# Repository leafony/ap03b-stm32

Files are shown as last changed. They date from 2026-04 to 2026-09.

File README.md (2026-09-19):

# Leafony AP03B STM32

STM32L452REI6を搭載した、Leafony AP03B STM32リーフのハードウェア設計リポジトリです。KiCadの回路図・PCBレイアウト、専用ライブラリ、部品表（BOM）を収録しています。

設計を開く場合は [KiCadプロジェクト](./kicad/leafony-ap03-stm32.kicad_pro)、部品を確認する場合は [BOM](./docs/leafony-ap03b-stm32-bom.csv) から参照してください。

## ハードウェア概要

| 項目 | 内容 |
| --- | --- |
| MCU | STMicroelectronics STM32L452REI6（U1） |
| CPU | Arm Cortex-M4、FPU搭載、最大80 MHz |
| メモリ | Flash 512 KB / SRAM 160 KB |
| MCUパッケージ | UFBGA-64、5 × 5 mm、0.5 mmピッチ |
| 低速外部クロック | 32.768 kHz水晶（X1） |
| 電源 | Leafonyバスの3.3 V / GND |
| バス接点 | CN1、表裏各29接点 |
| 主なバス信号 | D0〜D13、A0〜A5、SDA / SCL、SWDIO / SWCLK、RESET、AREF |
| 操作・表示 | BOOT0切り替えスイッチ、リセットスイッチ、BOOT0状態表示LED |
| 基板 | 20 × 20 mm、6層、板厚0.8 mm（PCB設計値） |
| 設計リビジョン | v1.0、2026-04-27（単体基板・回路図のタイトル欄） |

CPU・メモリの仕様は [STMicroelectronicsの製品情報](https://www.st.com/en/microcontrollers-microprocessors/stm32l452re.html)、実装部品と接続は本リポジトリの回路図・PCB・BOMを参照しています。最大クロックはMCUの仕様値で、実際の動作クロックはファームウェアの設定によります。

CN1のVBUS端子は未接続で、AREFの接続用抵抗R5は未実装（DNP）です。各端子の接続は [Leafonyバス回路図](./kicad/leafony_bus.kicad_sch) と [MCU回路図](./kicad/stm32.kicad_sch) で確認できます。

### スイッチとLED

| 部品 | 型番 | 回路上の役割 |
| --- | --- | --- |
| SW1（PG） | CUS-12TB | BOOT0のHigh / Lowを切り替える |
| SW2（RST） | EVQ-P7B01P | 押すとRESETをGNDへ接続する |
| D1 | SML-A12U8TT86 | BOOT0がHighのときに点灯する |

詳細は [リセット・プログラム切り替え回路](./kicad/reset_prog.kicad_sch) を参照してください。

## リポジトリ構成

| パス | 内容 |
| --- | --- |
| [kicad/leafony-ap03-stm32.kicad_pro](./kicad/leafony-ap03-stm32.kicad_pro) | 単体基板のKiCadプロジェクト |
| [kicad/leafony-ap03-stm32.kicad_sch](./kicad/leafony-ap03-stm32.kicad_sch) | トップレベル回路図。以下の3シートをまとめる |
| [kicad/stm32.kicad_sch](./kicad/stm32.kicad_sch) | MCU、電源、クロック周辺回路 |
| [kicad/leafony_bus.kicad_sch](./kicad/leafony_bus.kicad_sch) | Leafonyバス接点と信号接続 |
| [kicad/reset_prog.kicad_sch](./kicad/reset_prog.kicad_sch) | リセット、BOOT0切り替え、LED、信号切り替え回路 |
| [kicad/leafony-ap03-stm32.kicad_pcb](./kicad/leafony-ap03-stm32.kicad_pcb) | 単体基板のPCBレイアウト |
| [kicad/panelized/](./kicad/panelized/) | 面付け基板のプロジェクト・PCBレイアウト |
| [kicad/lib/](./kicad/lib/) | Leafony専用シンボル、フットプリント、3Dモデル配置先 |
| [docs/leafony-ap03b-stm32-bom.csv](./docs/leafony-ap03b-stm32-bom.csv) | 部品表（CSV） |
| [examples/](./examples/) | サンプルコード用ディレクトリ。現時点ではコード未収録 |

製品名はAP03Bですが、KiCadファイル名は `leafony-ap03-stm32` です。

## KiCadで開く

回路図とPCBは **KiCad 9.0** で保存されています。KiCad 9.0形式を読み込める環境と、KiCad標準のシンボル・フットプリントライブラリを用意してください。

1. リポジトリを取得します。

   ```sh
   git clone https://github.com/leafony/ap03b-stm32.git
   cd ap03b-stm32
   ```

2. KiCadで `kicad/leafony-ap03-stm32.kicad_pro` を開きます。
3. プロジェクト内の `.kicad_sch` を開くと回路図、`.kicad_pcb` を開くと基板レイアウトを確認できます。
4. 回路図のトップシートから「STM32 MCU」「Leafony Bus」「Reset Prog」の各階層シートへ移動します。

専用ライブラリは [sym-lib-table](./kicad/sym-lib-table) と [fp-lib-table](./kicad/fp-lib-table) に登録済みです。どちらも `${KIPRJMOD}/lib/` を参照するため、`kicad/` 以下のディレクトリ構成を保って開いてください。

### 面付け基板について

`kicad/panelized/` のPCBタイトル欄は「Leafony AP03 STM32 / 2025-07-06」で、単体基板の「Leafony AP03B STM32 / 2026-04-27」と異なります。製造に使用する場合は、単体基板の変更が反映されているか確認してください。

面付けプロジェクトを開くと `${KIPRJMOD}` の基準は `kicad/panelized/` になります。3Dモデルを表示する場合は、参照先が `kicad/lib/3dmodels/` に解決されるようにモデルパスを調整してください。

## 部品表（BOM）

[BOMのCSV](./docs/leafony-ap03b-stm32-bom.csv) には、部品番号（Reference）、値・型番（Value）、データシート、フットプリント、数量（Qty）、実装対象外の指定（DNP）、メーカー品番（MPN）、メーカー名（MANUFACTURER）を記載しています。

- `R5`、`R7`、`R12`、`R14` はDNP（未実装）です。
- `CN1` はBOMに含まれていません。バス接点の形状・接続は回路図とPCBを参照してください。
- 部品を変更した場合は、回路図と合わせてBOMも更新してください。

## 3Dモデルについて

一部部品の3Dモデルはライセンスの都合上公開できません。`kicad/lib/3dmodels/` にはモデル本体を収録していないため、必要に応じて別途入手し、以下のファイル名で配置してください。Leafony専用の回路図シンボルとフットプリントは同梱しています。

単体基板のPCBが参照するモデルは次のとおりです。

| 部品 | ファイル名（`kicad/lib/3dmodels/` 内） |
| --- | --- |
| U1：STM32L452REI6 | `UFBGA64-5x5mm.step` |
| U2：TS3A4751RUCR | `RUC0014A.stp` |
| SW1：CUS-12TB | `CUS-12TB.step` |
| SW2：EVQ-P7B01P | `EVQP7-KB-01P.STEP` |
| X1：32.768 kHz水晶 | `XTAL_NX2012SA_NDK.step` |
| Q1：RE1C002UNTCL | `DIO_RB558WMF_ROM.step` |
| D1：SML-A12U8TT86 | `SML-A12U8TT86P.stp` |

モデル名は既存のPCB参照に合わせたものです。入手したモデルのパッケージ形状を確認し、PCBエディターの3Dビューアーで位置・向き・縮尺を確認してください。3Dモデルがなくても回路図やPCBレイアウトは確認できます。

標準部品のモデルには `${KICAD8_3DMODEL_DIR}` の参照が残っています。KiCad 9では、旧バージョンの変数が未定義なら現行バージョンの対応する変数へ自動解決されます。表示されない場合は、標準3Dモデルライブラリの導入状況と「パスを設定」で古いパスが明示設定されていないか確認してください。詳細は [KiCad公式ドキュメントのパス設定](https://docs.kicad.org/9.0/en/kicad/kicad.html) を参照してください。

## ファームウェア・関連資料

このリポジトリには、ファームウェアのビルド設定や書き込みスクリプト、実行可能なサンプルコードは含まれていません。STM32 MCUリーフの開発環境については、Leafony公式資料を参照してください。

- [STM32 MCU スタートガイド](https://docs.leafony.com/getting-started/stm32/)
- [STM32 MCU向けArduino IDEの設定](https://docs.leafony.com/environment/stm32/arduino_ide/)
- [AP03 STM32 MCU 技術資料](https://docs.leafony.com/leaf/processor/ap03/)

上記のAP03向け資料を利用する際は、本リポジトリのAP03B回路図でピン接続や実装部品を確認してください。

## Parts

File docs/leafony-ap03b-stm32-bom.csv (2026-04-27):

Reference | Value | Datasheet | Footprint | Qty | DNP | MPN | MANUFACTURER
C1,C4,C6,C7,C8,C10 | 100nF(K)25V X5R | https://search.murata.co.jp/Ceramy/image/img/A01X/G101/ENG/GRM033R61E104KE14-01.pdf | Capacitor_SMD:C_0201_0603Metric | 6 |  | GRM033R61E104KE14D | Murata Electronics
C2,C3 | 6pF(D)50V C0G/NP0 | https://search.murata.co.jp/Ceramy/image/img/A01X/G101/ENG/GRM1555C1H6R0DA01-01.pdf | Capacitor_SMD:C_0402_1005Metric | 2 |  | GRM1555C1H6R0DA01D | Murata Electronics
C5 | 1uF(K)16V X6S | https://search.murata.co.jp/Ceramy/image/img/A01X/G101/ENG/GRM155C81C105KE11-01.pdf | Capacitor_SMD:C_0402_1005Metric | 1 |  | GRM155C81C105KE11D | Murata Electronics
C9 | 10uF(K)25V X5R | https://search.murata.co.jp/Ceramy/image/img/A01X/G101/ENG/GRM188R61E106KA73-01.pdf | Capacitor_SMD:C_0603_1608Metric | 1 |  | GRM188R61E106KA73D | Murata Electronics
C11 | 470nF(K)50V X5R | https://search.murata.co.jp/Ceramy/image/img/A01X/G101/ENG/GRM155R61H474KE11-01.pdf | Capacitor_SMD:C_0402_1005Metric | 1 |  | GRM155R61H474KE11D | Murata Electronics
D1 | SML-A12U8TT86 | https://fscdn.rohm.com/en/products/databook/datasheet/opto/led/chip_mono/sml-a12_a13.pdf | Leafony:LED_SML-A12_ROM | 1 |  | SML-A12U8TT86 | Rohm Semiconductor
D2 | 1SS387,L3F | https://toshiba.semicon-storage.com/info/1SS387_datasheet_en_20240617.pdf | Diode_SMD:D_SOD-523 | 1 |  | 1SS387,L3F | Toshiba Semiconductor and Storage
FB1 | MPZ1005S300CT000 | https://product.tdk.com/system/files/dam/doc/product/emc/emc/beads/catalog/emc_emc_mpz_en.pdf | Fuse:Fuse_0402_1005Metric | 1 |  | MPZ1005S300CT000 | TDK Corporation
Q1 | RE1C002UNTCL | https://fscdn.rohm.com/en/products/databook/datasheet/discrete/transistor/mosfet/re1c002un-e.pdf | Leafony:DIO_RB558WMF_ROM | 1 |  | RE1C002UNTCL | Rohm Semiconductor
R1,R2,R3,R8 | 10k(F) | https://www.yageo.com/upload/media/product/productsearch/datasheet/rchip/PYu-RC_Group_51_RoHS_L_12.pdf | Resistor_SMD:R_0402_1005Metric | 4 |  | RC0402FR-0710KL | YAGEO
R4,R11,R13 | 0R | https://www.yageo.com/upload/media/product/productsearch/datasheet/rchip/PYu-RC_Group_51_RoHS_L_12.pdf | Resistor_SMD:R_0402_1005Metric | 3 |  | RC0402JR-070RL | YAGEO
R5,R7,R12,R14 | DNP | ~ | Resistor_SMD:R_0402_1005Metric | 4 | DNP
R6 | 1k(F) | https://www.yageo.com/upload/media/product/productsearch/datasheet/rchip/PYu-RC_Group_51_RoHS_L_12.pdf | Resistor_SMD:R_0402_1005Metric | 1 |  | RC0402FR-071KL | YAGEO
R9 | 100R(F) | https://www.yageo.com/upload/media/product/productsearch/datasheet/rchip/PYu-RC_Group_51_RoHS_L_12.pdf | Resistor_SMD:R_0402_1005Metric | 1 |  | RC0402FR-07100RL | YAGEO
R10 | 100k(F) | https://www.yageo.com/upload/media/product/productsearch/datasheet/rchip/PYu-RC_Group_51_RoHS_L_12.pdf | Resistor_SMD:R_0402_1005Metric | 1 |  | RC0402FR-07100KL | YAGEO
SW1 | CUS-12TB | https://www.nidec-copal-electronics.com/eng/wp-content/uploads/2020/02/cus_e.pdf | Leafony:CUS-12TB_NDC | 1 |  | CUS-12TB | Nidec Components Corporation
SW2 | EVQ-P7B01P | https://industrial.panasonic.com/cdbs/www-data/pdf/ATK0000/ATK0000CE3.pdf | Leafony:EVQ-P7B01P | 1 |  | EVQ-P7B01P | Panasonic Electronic Components
U1 | STM32L452REI6 | https://www.st.com/resource/en/datasheet/stm32l452re.pdf | Package_BGA:UFBGA-64_5x5mm_Layout8x8_P0.5mm | 1 |  | STM32L452REI6 | STMicroelectronics
U2 | TS3A4751RUCR | https://www.ti.com/lit/gpn/ts3a4751 | Leafony:RUC14 | 1 |  | TS3A4751RUCR | Texas Instruments
X1 | MU00530-32.768K | https://www.ndk.com/images/products/catalog/c_NX2012SA-EXS00A_e.pdf | Crystal:Crystal_SMD_2012-2Pin_2.0x1.2mm | 1 |  | MU00530-32.768K | NDK America, Inc.

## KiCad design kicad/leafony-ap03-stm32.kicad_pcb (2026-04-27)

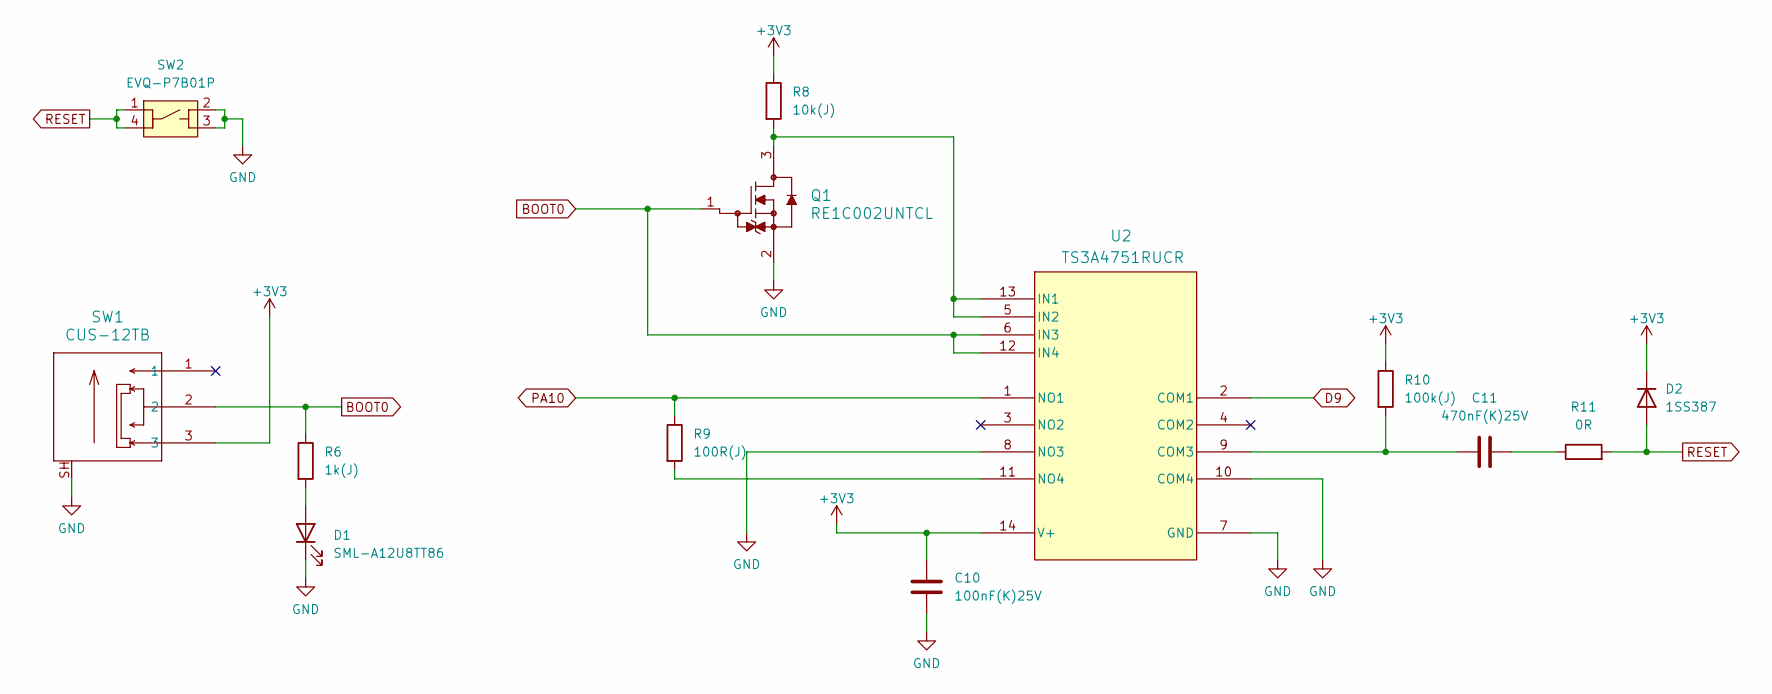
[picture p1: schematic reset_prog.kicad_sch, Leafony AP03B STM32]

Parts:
C10: 100nF(K)25V; C_0201_0603Metric
C11: 470nF(K)25V; C_0402_1005Metric
D1: SML-A12U8TT86; LED_SML-A12_ROM
D2: 1SS387; D_SOD-523
Q1: RE1C002UNTCL; DIO_RB558WMF_ROM
R6: 1k(J); R_0402_1005Metric
R8: 10k(J); R_0402_1005Metric
R9: 100R(J); R_0402_1005Metric
R10: 100k(J); R_0402_1005Metric
R11: 0R; R_0402_1005Metric
SW1: CUS-12TB; CUS-12TB_NDC
SW2: EVQ-P7B01P
U2: TS3A4751RUCR; RUC14

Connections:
+3V3: C10.1, D2.1 (K), R8.1, R10.1, SW1.3, U2.14 (V+); also elsewhere on the board
BOOT0: Q1.1, R6.1, SW1.2, U2.6 (IN3), U2.12 (IN4); also elsewhere on the board
D9: U2.2 (COM1); also elsewhere on the board
GND: C10.2, D1.1 (K), Q1.2, SW1.SH, SW2.2, SW2.3, U2.7 (GND), U2.8 (NO3), U2.10 (COM4); also elsewhere on the board
unnamed: C11.2, R11.1
unnamed: D1.2 (A), R6.2
unnamed: C11.1, R10.2, U2.9 (COM3)
unnamed: Q1.3, R8.2, U2.5 (IN2), U2.13 (IN1)
unnamed: R9.2, U2.11 (NO4)
PA10: R9.1, U2.1 (NO1); also elsewhere on the board
RESET: D2.2 (A), R11.2, SW2.1, SW2.4; also elsewhere on the board

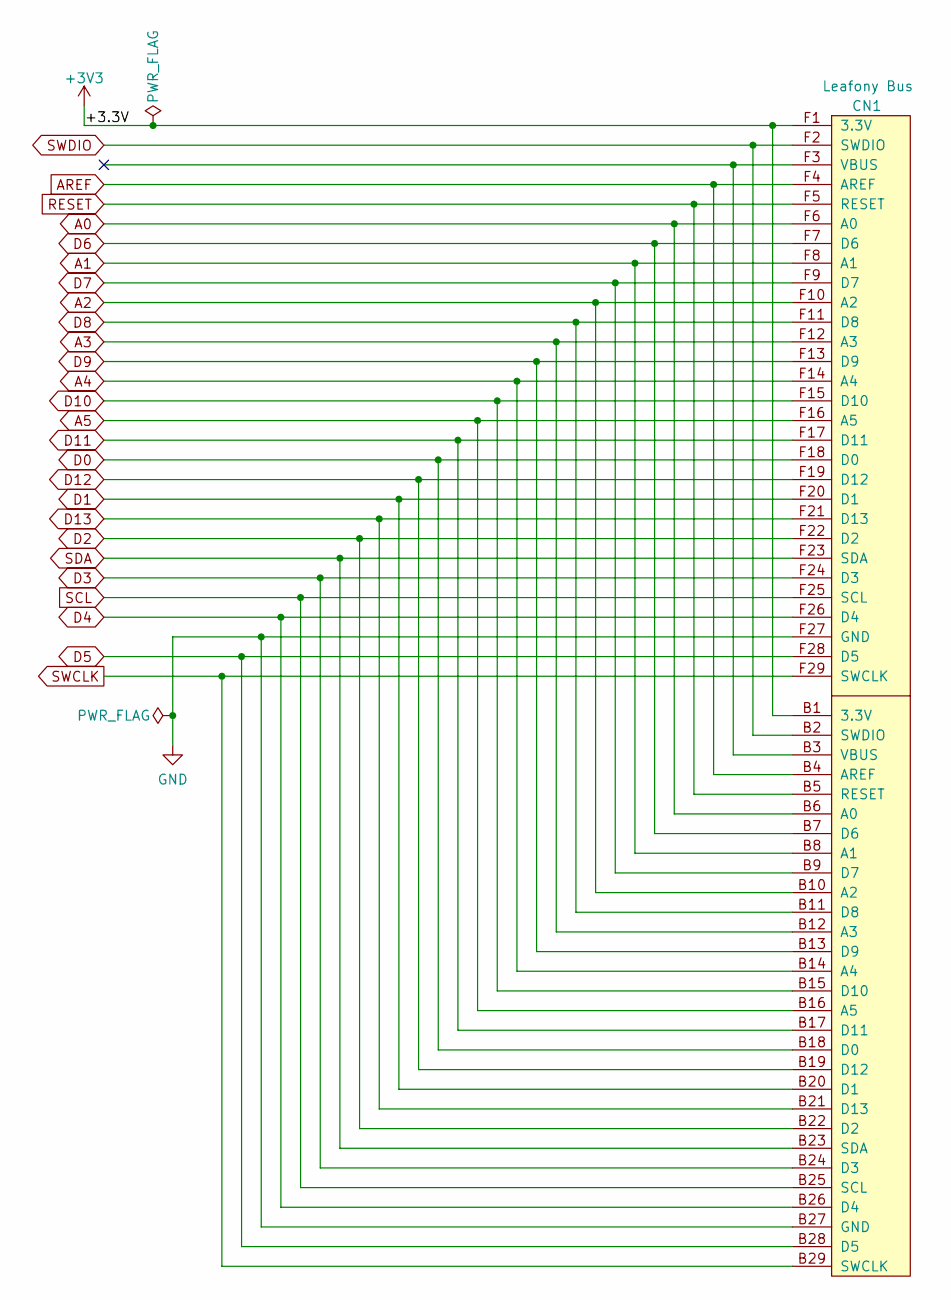
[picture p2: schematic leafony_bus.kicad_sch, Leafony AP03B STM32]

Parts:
CN1: Leafony Bus; CN_F29_B29

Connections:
+3V3: CN1.B1 (3.3V), CN1.F1 (3.3V); also elsewhere on the board
A0: CN1.B6 (A0), CN1.F6 (A0); also elsewhere on the board
A1: CN1.B8 (A1), CN1.F8 (A1); also elsewhere on the board
A2: CN1.B10 (A2), CN1.F10 (A2); also elsewhere on the board
A3: CN1.B12 (A3), CN1.F12 (A3); also elsewhere on the board
A4: CN1.B14 (A4), CN1.F14 (A4); also elsewhere on the board
A5: CN1.B16 (A5), CN1.F16 (A5); also elsewhere on the board
AREF: CN1.B4 (AREF), CN1.F4 (AREF); also elsewhere on the board
D0: CN1.B18 (D0), CN1.F18 (D0); also elsewhere on the board
D1: CN1.B20 (D1), CN1.F20 (D1); also elsewhere on the board
D2: CN1.B22 (D2), CN1.F22 (D2); also elsewhere on the board
D3: CN1.B24 (D3), CN1.F24 (D3); also elsewhere on the board
D4: CN1.B26 (D4), CN1.F26 (D4); also elsewhere on the board
D5: CN1.B28 (D5), CN1.F28 (D5); also elsewhere on the board
D6: CN1.B7 (D6), CN1.F7 (D6); also elsewhere on the board
D7: CN1.B9 (D7), CN1.F9 (D7); also elsewhere on the board
D8: CN1.B11 (D8), CN1.F11 (D8); also elsewhere on the board
D9: CN1.B13 (D9), CN1.F13 (D9); also elsewhere on the board
D10: CN1.B15 (D10), CN1.F15 (D10); also elsewhere on the board
D11: CN1.B17 (D11), CN1.F17 (D11); also elsewhere on the board
D12: CN1.B19 (D12), CN1.F19 (D12); also elsewhere on the board
D13: CN1.B21 (D13), CN1.F21 (D13); also elsewhere on the board
GND: CN1.B27 (GND), CN1.F27 (GND); also elsewhere on the board
RESET: CN1.B5 (RESET), CN1.F5 (RESET); also elsewhere on the board
SCL: CN1.B25 (SCL), CN1.F25 (SCL); also elsewhere on the board
SDA: CN1.B23 (SDA), CN1.F23 (SDA); also elsewhere on the board
SWCLK: CN1.B29 (SWCLK), CN1.F29 (SWCLK); also elsewhere on the board
SWDIO: CN1.B2 (SWDIO), CN1.F2 (SWDIO); also elsewhere on the board

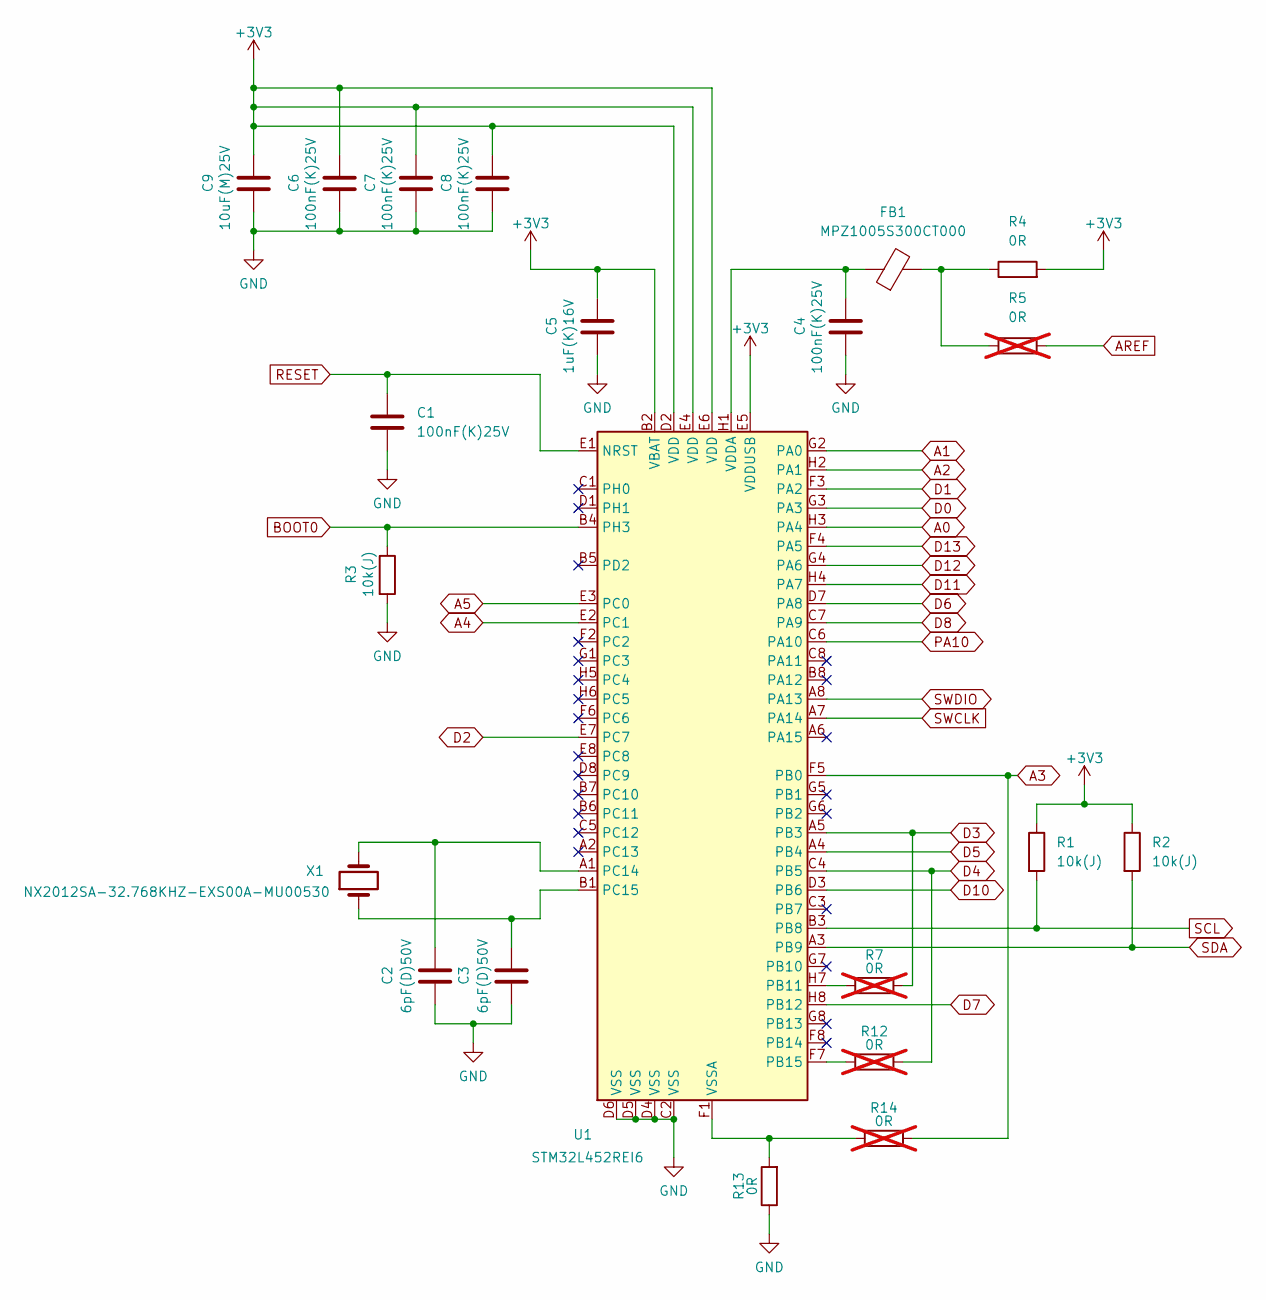
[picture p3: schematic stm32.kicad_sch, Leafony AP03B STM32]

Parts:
C1, C4, C6, C7, C8: 100nF(K)25V; C_0201_0603Metric
C2, C3: 6pF(D)50V; C_0402_1005Metric
C5: 1uF(K)16V; C_0402_1005Metric
C9: 10uF(M)25V; C_0603_1608Metric
FB1: MPZ1005S300CT000; Fuse_0402_1005Metric
R1, R2, R3: 10k(J); R_0402_1005Metric
R4, R13: 0R; R_0402_1005Metric
R5, R7, R12, R14: 0R; R_0402_1005Metric; not fitted
U1: STM32L452REI6; UFBGA-64_5x5mm_Layout8x8_P0.5mm
X1: NX2012SA-32.768KHZ-EXS00A-MU00530; Crystal_SMD_2012-2Pin_2.0x1.2mm

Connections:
+3V3: C5.1, C6.1, C7.1, C8.1, C9.1, R1.1, R2.1, R4.2, U1.B2 (VBAT), U1.D2 (VDD), U1.E4 (VDD), U1.E5 (VDDUSB), U1.E6 (VDD); also elsewhere on the board
A0: U1.H3 (PA4); also elsewhere on the board
A1: U1.G2 (PA0); also elsewhere on the board
A2: U1.H2 (PA1); also elsewhere on the board
A3: R14.2, U1.F5 (PB0); also elsewhere on the board
A4: U1.E2 (PC1); also elsewhere on the board
A5: U1.E3 (PC0); also elsewhere on the board
AREF: R5.2; also elsewhere on the board
BOOT0: R3.1, U1.B4 (PH3); also elsewhere on the board
D0: U1.G3 (PA3); also elsewhere on the board
D1: U1.F3 (PA2); also elsewhere on the board
D2: U1.E7 (PC7); also elsewhere on the board
D3: R7.2, U1.A5 (PB3); also elsewhere on the board
D4: R12.2, U1.C4 (PB5); also elsewhere on the board
D5: U1.A4 (PB4); also elsewhere on the board
D6: U1.D7 (PA8); also elsewhere on the board
D7: U1.H8 (PB12); also elsewhere on the board
D8: U1.C7 (PA9); also elsewhere on the board
D10: U1.D3 (PB6); also elsewhere on the board
D11: U1.H4 (PA7); also elsewhere on the board
D12: U1.G4 (PA6); also elsewhere on the board
D13: U1.F4 (PA5); also elsewhere on the board
GND: C1.2, C2.2, C3.2, C4.2, C5.2, C6.2, C7.2, C8.2, C9.2, R3.2, R13.1, U1.C2 (VSS), U1.D4 (VSS), U1.D5 (VSS), U1.D6 (VSS); also elsewhere on the board
unnamed: FB1.2, R4.1, R5.1
unnamed: R7.1, U1.H7 (PB11)
unnamed: R12.1, U1.F7 (PB15)
unnamed: C2.1, U1.A1 (PC14), X1.2
unnamed: C3.1, U1.B1 (PC15), X1.1
unnamed: C4.1, FB1.1, U1.H1 (VDDA)
unnamed: R13.2, R14.1, U1.F1 (VSSA)
PA10: U1.C6 (PA10); also elsewhere on the board
RESET: C1.1, U1.E1 (NRST); also elsewhere on the board
SCL: R1.2, U1.B3 (PB8); also elsewhere on the board
SDA: R2.2, U1.A3 (PB9); also elsewhere on the board
SWCLK: U1.A7 (PA14); also elsewhere on the board
SWDIO: U1.A8 (PA13); also elsewhere on the board

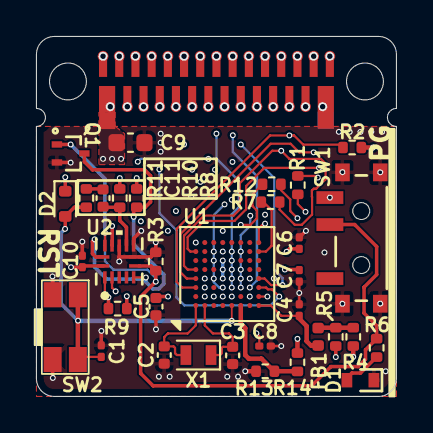
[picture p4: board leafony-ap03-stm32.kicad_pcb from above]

Board: 6 copper layers, 20.0 x 20.0 mm, 35 parts (0 on the bottom side), 42 nets.

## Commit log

2026-04-27 回路図・レイアウトを追加
    [leafony-ap03-stm32.kicad_pcb, leafony-ap03-stm32.kicad_sch, leafony_bus.kicad_sch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]
2026-04-27 BOMを追加
    [leafony-ap03b-stm32-bom.csv, reset_prog.kicad_sch, stm32.kicad_sch]
2026-04-27 BOMからCN1を除外
    [leafony-ap03b-stm32-bom.csv, leafony_bus.kicad_sch]
2026-09-19 README.mdを更新し、ハードウェア概要、スイッチとLEDの詳細、リポジトリ構成、3Dモデル情報、ファームウェア・関連資料を追加
2026-11-07 KiCadプロジェクト名を変更
2026-11-07 穴の直径を0.5から0.56に変更
2026-11-07 BOMとCPLを更新
2026-11-12 回路図・レイアウトPDFを自動生成するCIを追加
2026-11-12 CIで生成した回路図・レイアウトPDFを追加
